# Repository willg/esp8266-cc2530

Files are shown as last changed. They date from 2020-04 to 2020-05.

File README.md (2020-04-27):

# ESP8266 + CC2530
Board to integrate an ESP8266 + CC2530 + RF Front end

# RF Parts
[CC2530F256(radio)](https://lcsc.com/product-detail/RF-Transceiver-ICs_Texas-Instruments_CC2530F256RHAR_Texas-Instruments-TI-CC2530F256RHAR_C9120.html/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)

## RF Front Ends
### RFX2401C
[RFX2401C](https://lcsc.com/product-detail/RF-Transceiver-ICs_Skyworks-Solutions_RFX2401C_Skyworks-Solutions-RFX2401C_C19213.html/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)

> This is the RF front end that was on the 2530PA module I got from
> [Bangood](https://www.banggood.com/CC2530-UART-Wireless-Core-Development-Board-CC2530F256-Serial-Port-Wireless-Module-2_4GHz-For-Zigbee-p-1445025.html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),

RFX2401C Mode Truth Table:
| TXEN | RXEN | Mode |
| --- | --- | --- |
| 1 | X | TX Active
| 0 | 1 | RX Active
| 0 | 0 | Chip shutdown

CC2530 Control Connections **UNTESTED**:
| CC2530 | RFX2401C |
| --- | --- |
| P1_0 | RXEN
| P1_1 | TXEN

### CC2592
[CC2592](https://lcsc.com/product-detail/RF-Transceiver-ICs_Texas-Instruments_CC2592RGVR_Texas-Instruments-TI-CC2592RGVR_C53274.html/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)

CC2592 Mode Truth Table:
| PA_EN | LNA_EN | HGM | Mode |
| --- | --- | --- | --- |
| 0 | 0 | X | Power Down
| X | 1 | 0 | RX Low-gain
| X | 1 | 1 | RX High-gain
| 1 | 0 | X | TX

CC2530 Control Connections:
| CC2592 | CC2530 |
| --- | --- |
| EN (LNA_EN) | P1_0
| PA_EN | P1_1
| HGM | P0_7
[Source](https://processors.wiki.ti.com/index.php/Enabling_the_Support_of_CC259x_PA/LNA_with_Z-Stack-Home)

### CC2591
This part is not recommended for new designs, and is out of stock at LCSC

## Regulator
[AMS1117-3.3](https://lcsc.com/product-detail/Low-Dropout-Regulators-LDO_AMS_AMS1117-3-3_AMS1117-3-3_C6186.html/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)

AMS1117-3.3 Bypass. >22uF Tantalum 
[100uF 6.3V](https://lcsc.com/product-detail/Tantalum-Capacitors_AVX_TAJB107K006RNJ_100uF-107-10-6-3V_C16133.html/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)

# ESP8266
## Option 1
Use Wemos D1-mini and interface via header

## Option 2
Use ESP8266MOD and integrate onto board
[ESP8266MOD](https://lcsc.com/product-detail/WIFI-Modules_ESP-12F-ESP8266MOD_C82891.html)
> not available for JLPCB to assemble

[CH340C (USB-UART
bridge)](https://lcsc.com/product-detail/USB_CH340C_C84681.html/?href=jlc-SMT)

# CC2530PA Notes
CC2530PA from banggood's connections:
| RFX2401C | CC2530 |
| --- | --- |
| TXEN | P1_5
| RXEN | P1_4

> I modified the z-stack zigbee firmware to have TXEN on PA1_5 and RXEN on P1_4
> and improved RF performance over the stock CC2530_CC2592 firmware, and seemed
> to be better than the CC2531 USB stick I have

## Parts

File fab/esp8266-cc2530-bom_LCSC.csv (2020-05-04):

Comment | Designator | Footprint | LCSC
18p | C14,C13 | Capacitor_SMD:C_0805_2012Metric | C1797
1p | C15,C16 | Capacitor_SMD:C_0805_2012Metric | C14971
2.0p | C18 | Capacitor_SMD:C_0805_2012Metric | C1800
100u | C2 | Capacitor_Tantalum_SMD:CP_EIA-3528-21_Kemet-B | C16133
1u | C4,C20,C19,C3,C7,C11,C5,C1,C12 | Capacitor_SMD:C_0805_2012Metric | C28323
15p | C6,C8 | Capacitor_SMD:C_0805_2012Metric | C1794
27p | C9,C10 | Capacitor_SMD:C_0805_2012Metric | C8031
B5819W | D1 | Diode_SMD:D_SOD-123 | C8598
56k | R2 | Resistor_SMD:R_0805_2012Metric | C17756
1k | R4,R3 | Resistor_SMD:R_0805_2012Metric | C17513
AMS1117-3.3 | U2 | Package_TO_SOT_SMD:SOT-223-3_TabPin2 | C6186
CC2530Fxxx | U3 | Package_DFN_QFN:QFN-40-1EP_6x6mm_P0.5mm_EP4.6x4.6mm | C9120
RFX2401C | U4 | Package_DFN_QFN:QFN-16-1EP_3x3mm_P0.5mm_EP1.7x1.7mm | C19213
32.768kHz | Y1 | Crystal:Crystal_SMD_3215-2Pin_3.2x1.5mm | C32346
32MHz | Y2 | Crystal:Crystal_SMD_SeikoEpson_FA238-4Pin_3.2x2.5mm | C91742

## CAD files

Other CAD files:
dxfs/TW5-2-5_pcbOutline.dxf
TW4-2-8_pcbOutline.dxf
dxfs/TW5-2-5_case.dxf

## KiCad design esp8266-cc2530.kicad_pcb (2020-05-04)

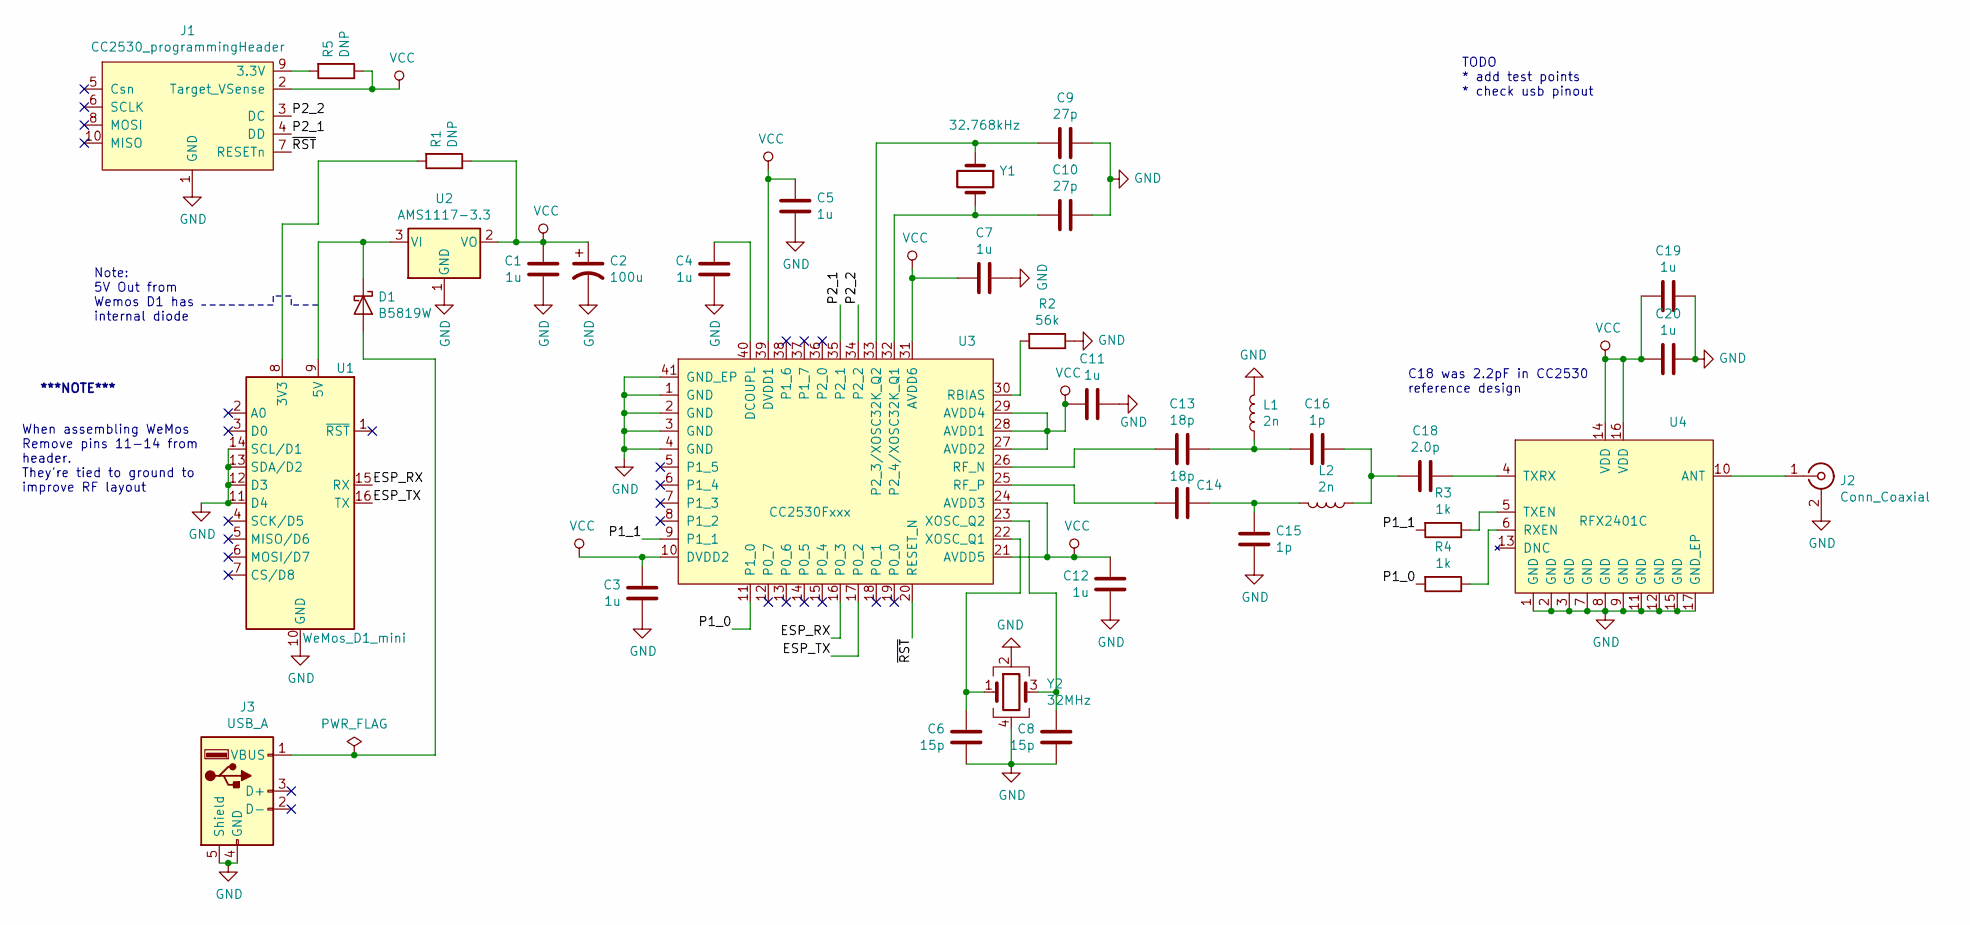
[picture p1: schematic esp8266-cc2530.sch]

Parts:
C1, C3, C4, C5, C7, C11, C12, C19, C20: 1u; C_0805_2012Metric; LCSC C28323
C2: 100u; CP_EIA-3528-21_Kemet-B; LCSC C16133
C6, C8: 15p; C_0805_2012Metric; JLCPCB Basic Y
C9, C10: 27p; C_0805_2012Metric; JLCPCB Basic Y
C13, C14: 18p; C_0805_2012Metric; JLCPCB Basic Y
C15, C16: 1p; C_0805_2012Metric; JLCPCB Basic Y
C18: 2.0p; C_0805_2012Metric; LCSC C1800
D1: B5819W; D_SOD-123; LCSC C8598
J1: CC2530_programmingHeader; PinHeader_2x05_P1.27mm_Vertical_SMD; LCSC C124391
J2: Conn_Coaxial; CON-SMA-EDGE-S(RP)
J3: USB_A; Molex_48037-2200_USB-A
L1, L2: 2n; L_0603_1608Metric; JLCPCB Basic No JLCPCB Assembly
R1, R5: DNP; R_0805_2012Metric
R2: 56k; R_0805_2012Metric; JLCPCB Basic Y
R3, R4: 1k; R_0805_2012Metric; JLCPCB Basic Y
U1: WeMos_D1_mini; WEMOS_D1_mini_smt
U2: AMS1117-3.3; SOT-223-3_TabPin2; LCSC C6186
U3: CC2530Fxxx; QFN-40-1EP_6x6mm_P0.5mm_EP4.6x4.6mm; LCSC C9120
U4: RFX2401C; QFN-16-1EP_3x3mm_P0.5mm_EP1.7x1.7mm; LCSC C19213
Y1: 32.768kHz; Crystal_SMD_3215-2Pin_3.2x1.5mm; LCSC C32346
Y2: 32MHz; Crystal_SMD_SeikoEpson_FA238-4Pin_3.2x2.5mm; LCSC C91742

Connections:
/ESP_RX: U1.15 (RX), U3.16 (P0_3)
/ESP_TX: U1.16 (TX), U3.17 (P0_2)
/P1_0: R4.2, U3.11 (P1_0)
/P1_1: R3.2, U3.9 (P1_1)
/P2_1: J1.4 (DD), U3.35 (P2_1)
/P2_2: J1.3 (DC), U3.34 (P2_2)
/~RST: J1.7 (RESETn), U3.20 (RESET_N)
GND: C1.1, C2.2, C3.1, C4.1, C5.2, C6.1, C7.2, C8.1, C9.1, C10.1, C11.2, C12.1, C15.2, C19.2, C20.2, J1.1 (GND), J2.2 (Ext), J3.4 (GND), J3.5 (Shield), L1.2, R2.1, U1.10 (GND), U1.11 (D4), U1.12 (D3), U1.13 (SDA/D2), U1.14 (SCL/D1), U2.1 (GND), U3.1 (GND), U3.2 (GND), U3.3 (GND), U3.4 (GND), U3.41 (GND_EP), U4.1 (GND), U4.2 (GND), U4.3 (GND), U4.7 (GND), U4.8 (GND), U4.9 (GND), U4.11 (GND), U4.12 (GND), U4.15 (GND), U4.17 (GND_EP), Y2.2, Y2.4
unnamed: C4.2, U3.40 (DCOUPL)
unnamed: C6.2, U3.22 (XOSC_Q1), Y2.1
unnamed: C8.2, U3.23 (XOSC_Q2), Y2.3
unnamed: C9.2, U3.33 (P2_3/XOSC32K_Q2), Y1.1
unnamed: C10.2, U3.32 (P2_4/XOSC32K_Q1), Y1.2
unnamed: C13.1, U3.26 (RF_N)
unnamed: C13.2, C16.1, L1.1
unnamed: C14.1, U3.25 (RF_P)
unnamed: C14.2, C15.1, L2.2
unnamed: C16.2, C18.1, L2.1
unnamed: C18.2, U4.4 (TXRX)
unnamed: D1.1 (K), U1.9 (5V), U2.3 (VI)
unnamed: D1.2 (A), J3.1 (VBUS)
unnamed: J1.9 (3.3V), R5.2
unnamed: J2.1 (In), U4.10 (ANT)
unnamed: R1.2, U1.8 (3V3)
unnamed: R2.2, U3.30 (RBIAS)
unnamed: R3.1, U4.5 (TXEN)
unnamed: R4.1, U4.6 (RXEN)
VCC: C1.2, C2.1, C3.2, C5.1, C7.1, C11.1, C12.2, C19.1, C20.1, J1.2 (Target_VSense), R1.1, R5.1, U2.2 (VO), U3.10 (DVDD2), U3.21 (AVDD5), U3.24 (AVDD3), U3.27 (AVDD2), U3.28 (AVDD1), U3.29 (AVDD4), U3.31 (AVDD6), U3.39 (DVDD1), U4.14 (VDD), U4.16 (VDD)

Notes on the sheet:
TODO * add test points * check usb pinout
C18 was 2.2pF in CC2530 reference design
***NOTE***
When assembling WeMos Remove pins 11-14 from header. They're tied to ground to improve RF layout
Note: 5V Out from Wemos D1 has internal diode

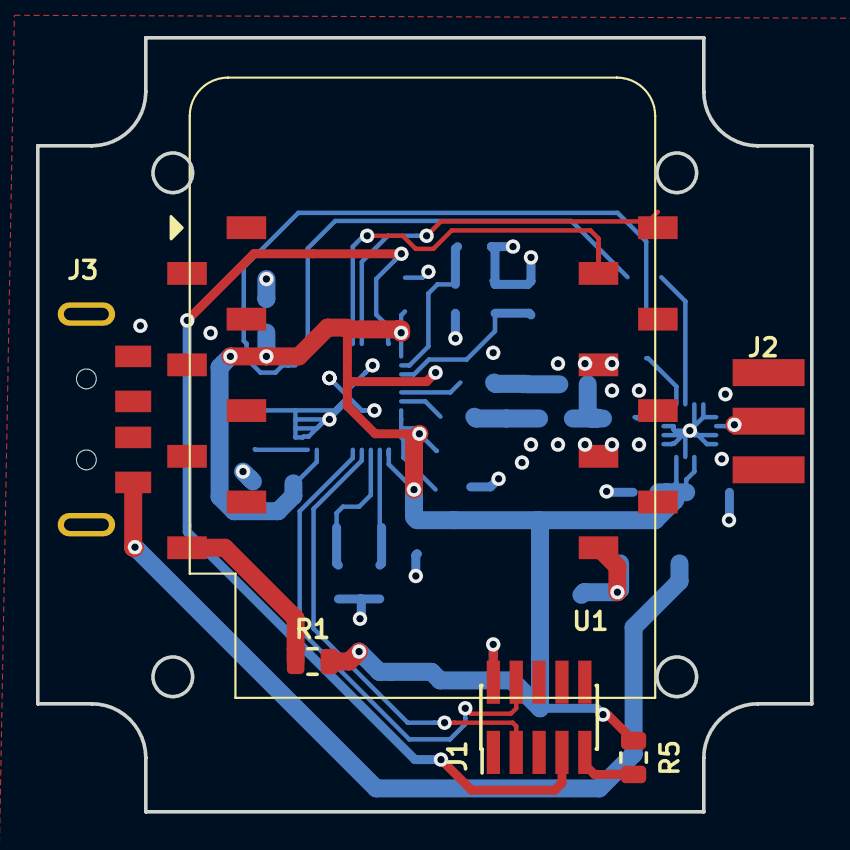
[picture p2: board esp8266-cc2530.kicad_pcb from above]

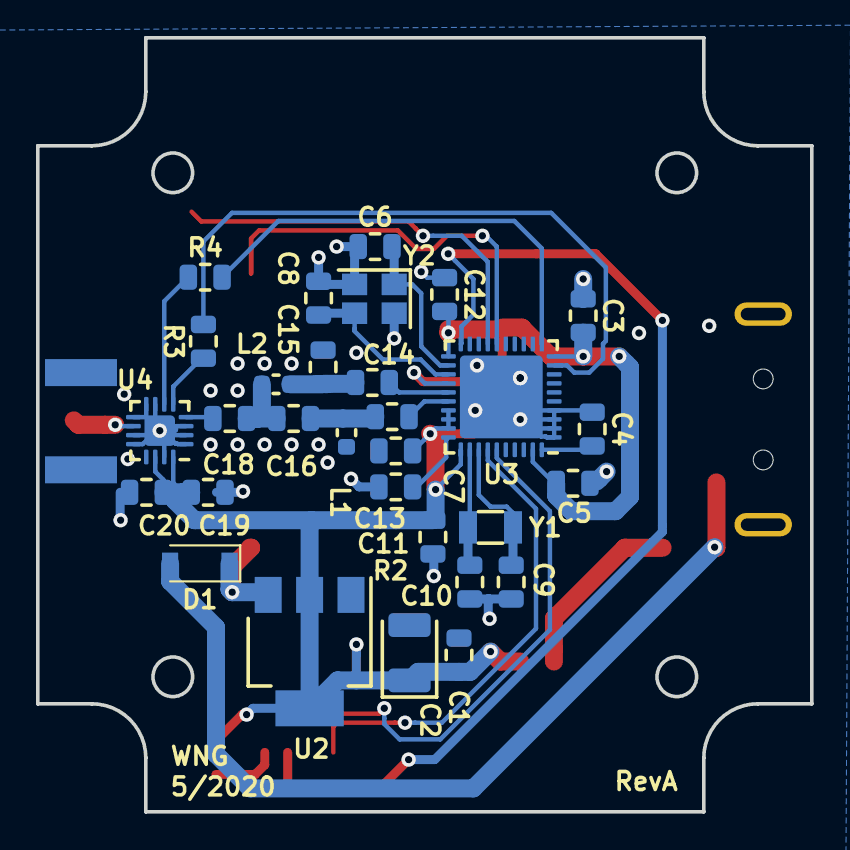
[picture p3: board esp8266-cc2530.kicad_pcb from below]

Board: 2 copper layers, 43.0 x 43.0 mm, 36 parts (30 on the bottom side), 28 nets.

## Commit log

2020-04-24 created cc2592 part, added to schematic undecided if RF frontend should be RFX2401 or CC2592
    [esp8266-cc2530.sch]
2020-04-26 schematic updates * updated TODO * added bypass to RF2401
    [esp8266-cc2530.sch]
2020-04-26 add cc2530 programming header
    [esp8266-cc2530.sch]
2020-04-27 added regulator for cc2530
    [esp8266-cc2530.sch]
2020-04-27 remove cc2592 from schematic
    [esp8266-cc2530.sch]
2020-04-27 annotated schematic, fixed DRCs, needed to fork D1-mini symbol
    [esp8266-cc2530.sch]
2020-04-27 begining to assign LCSC part numbers
    [esp8266-cc2530.sch]
2020-04-27 footprints assigned to all parts
    [esp8266-cc2530.sch]
2020-04-28 added sma connector
    [esp8266-cc2530.sch]
2020-04-28 starting to place components. added dxf for potential case
    [TW4-2-8_pcbOutline.dxf, esp8266-cc2530.kicad_pcb, esp8266-cc2530.sch]
2020-04-28 removed RFX2401 bypass, added DNP to power CC2530 from debugger
    [esp8266-cc2530.sch]
2020-04-28 progress on layout
    [esp8266-cc2530.kicad_pcb]
2020-04-30 board laid out
    [esp8266-cc2530.kicad_pcb]
2020-05-01 fixed SMA connector footprint and added 3d model.
    thinking of changing cases... extra board outlines on edge.cuts
    [esp8266-cc2530.kicad_pcb, esp8266-cc2530.sch]
2020-05-02 updated layout * new WEMOS D1 footprint and 3d model * switched to case TW5-2-5
    [TW5-2-5_case.dxf, TW5-2-5_pcbOutline.dxf, esp8266-cc2530.kicad_pcb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]
2020-05-02 added usb connector, not routed yet
    [esp8266-cc2530.kicad_pcb, esp8266-cc2530.sch]
2020-05-03 usb connector routed out
    [esp8266-cc2530.kicad_pcb]
2020-05-04 updated design rules
    [esp8266-cc2530.kicad_pcb]
2020-05-04 remove *.csv from .gitignore to track fabrication files
2020-05-04 add fabrication output
    [esp8266-cc2530-B_Cu.gbr, esp8266-cc2530-B_Mask.gbr, esp8266-cc2530-B_Paste.gbr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]
2020-05-08 add GND_EP pin to CC2592
2020-05-08 verified usb connector pinout
    [esp8266-cc2530.sch]
